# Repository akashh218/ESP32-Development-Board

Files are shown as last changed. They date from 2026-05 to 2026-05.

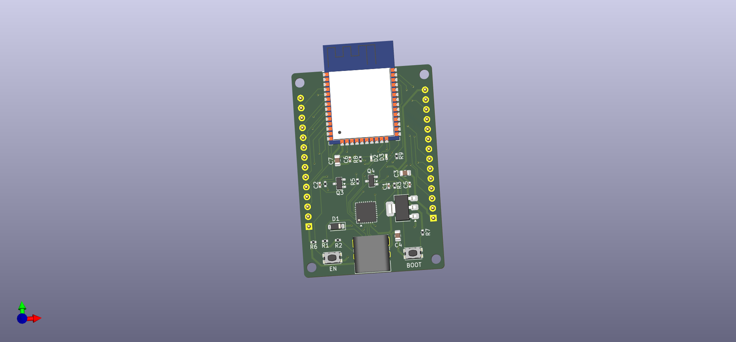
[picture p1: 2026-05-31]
esp32/esp32.png

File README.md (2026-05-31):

# ESP32-WROOM Development Board

## Overview

This project is a custom ESP32-WROOM development board designed for embedded systems, IoT applications, robotics, and rapid prototyping. The board integrates essential support circuitry required for programming, debugging, power management, and peripheral interfacing, providing a reliable platform for ESP32-based development.

## Features

* ESP32-WROOM module
* USB Type-C interface for power and programming
* USB-to-UART converter for firmware upload and serial debugging
* 3.3V regulated power supply
* Reset and Boot buttons
* GPIO breakout headers
* I²C expansion support
* UART communication interface
* Motor driver connectivity
* Status and power indicator LEDs
* Compact and PCB-friendly design

## Hardware Specifications

| Parameter | Value |
| --- | --- |
| Microcontroller | ESP32-WROOM |
| Operating Voltage | 3.3V |
| Input Power | 5V USB Type-C |
| Wireless Connectivity | Wi-Fi 802.11 b/g/n, Bluetooth Classic, BLE |
| Programming Interface | USB-to-UART |
| GPIO Access | Available through expansion headers |

## Applications

* Home Automation
* IoT Devices
* Robotics
* Sensor Networks
* Industrial Monitoring
* Wireless Data Acquisition
* Smart Control Systems
* Embedded Learning and Prototyping

## PCB Design

The PCB was designed to provide:

* Stable power delivery
* Reliable ESP32 operation
* Easy firmware flashing
* Expansion for future peripherals
* Compact layout suitable for custom projects

## Repository Contents

* Schematics
* PCB Layout Files
* Gerber Files
* Bill of Materials (BOM)
* Assembly Documentation
* Hardware Images

## Getting Started

1. Connect the board using a USB Type-C cable.
2. Install ESP32 drivers if required.
3. Open Arduino IDE, PlatformIO, or ESP-IDF.
4. Select the appropriate ESP32 board configuration.
5. Upload your firmware.
6. Monitor serial output for debugging.

## Author

Designed and developed by Akash.

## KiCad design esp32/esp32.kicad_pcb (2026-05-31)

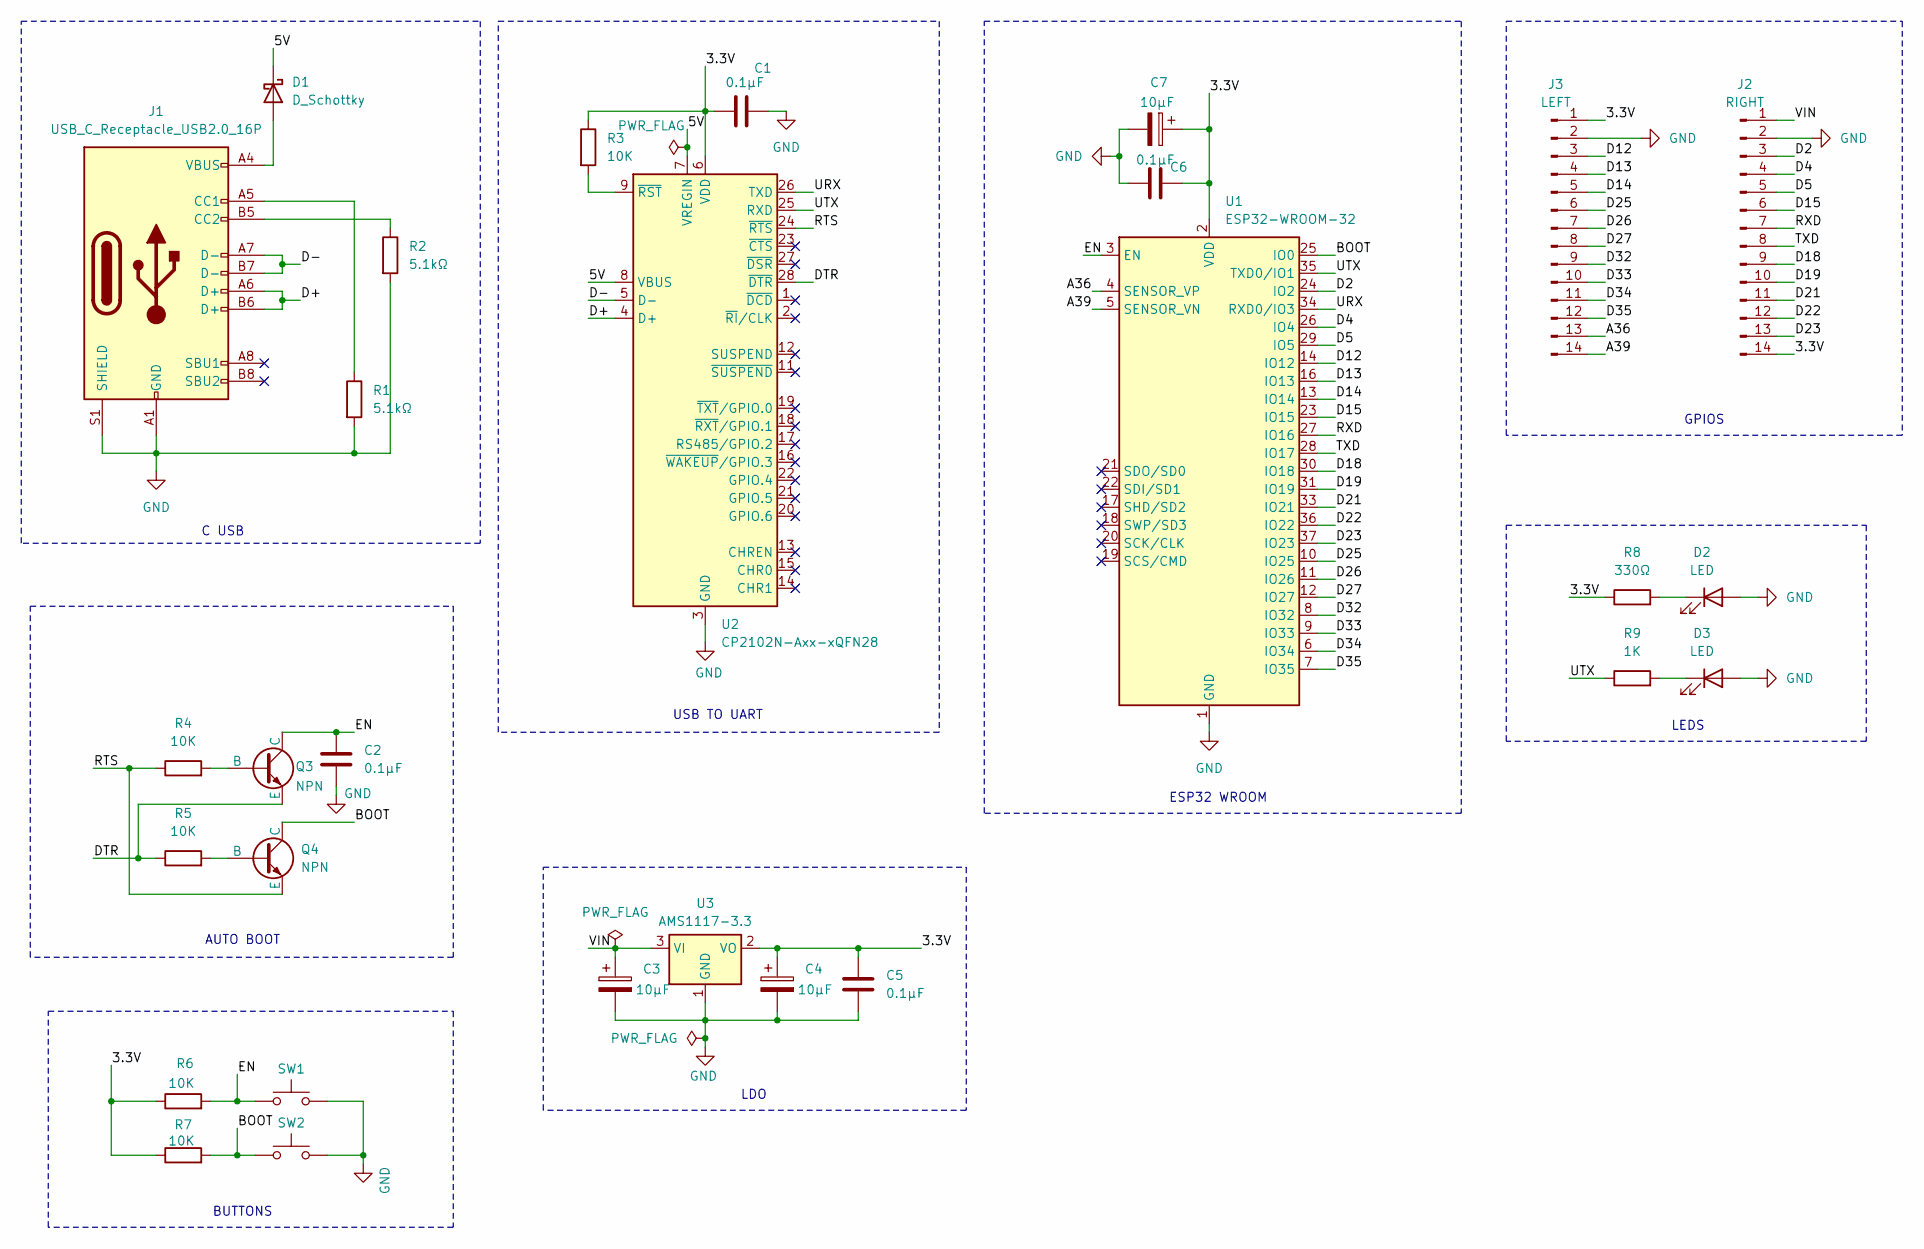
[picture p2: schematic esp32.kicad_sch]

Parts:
C1, C2, C5, C6: 0.1µF; C_0402_1005Metric
C3, C4, C7: 10µF; C_0805_2012Metric
D1: D_Schottky; D_SOD-123
D2, D3: LED; LED_0402_1005Metric
J1: USB_C_Receptacle_USB2.0_16P; USB_C_Receptacle_GCT_USB4085
J2: RIGHT; PinHeader_1x14_P2.54mm_Vertical
J3: LEFT; PinHeader_1x14_P2.54mm_Vertical
Q3, Q4: NPN; SOT-23
R1, R2: 5.1kΩ; R_0402_1005Metric
R3, R4, R5, R6, R7: 10K; R_0402_1005Metric
R8: 330Ω; R_0402_1005Metric
R9: 1K; R_0402_1005Metric
SW1, SW2: SW_Push; SW_Push_1P1T_NO_CK_KMR2
U1: ESP32-WROOM-32
U2: CP2102N-Axx-xQFN28; QFN-28-1EP_5x5mm_P0.5mm_EP3.35x3.35mm
U3: AMS1117-3.3; SOT-223-3_TabPin2

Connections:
/3.3V: C1.1, C4.1, C5.1, C6.2, C7.1, J2.14, J3.1, R3.1, R6.1, R7.1, R8.1, U1.2 (VDD), U2.6 (VDD), U3.2 (VO)
/5V: D1.1 (K), U2.7 (VREGIN), U2.8 (VBUS)
/A36: J3.13, U1.4 (SENSOR_VP)
/A39: J3.14, U1.5 (SENSOR_VN)
/BOOT: Q4.1 (C), R7.2, SW2.1, U1.25 (IO0); also elsewhere on the board
/D2: J2.3, U1.24 (IO2)
/D4: J2.4, U1.26 (IO4)
/D5: J2.5, U1.29 (IO5)
/D12: J3.3, U1.14 (IO12)
/D13: J3.4, U1.16 (IO13)
/D14: J3.5, U1.13 (IO14)
/D15: J2.6, U1.23 (IO15)
/D18: J2.9, U1.30 (IO18)
/D19: J2.10, U1.31 (IO19)
/D21: J2.11, U1.33 (IO21)
/D22: J2.12, U1.36 (IO22)
/D23: J2.13, U1.37 (IO23)
/D25: J3.6, U1.10 (IO25)
/D26: J3.7, U1.11 (IO26)
/D27: J3.8, U1.12 (IO27)
/D32: J3.9, U1.8 (IO32)
/D33: J3.10, U1.9 (IO33)
/D34: J3.11, U1.6 (IO34)
/D35: J3.12, U1.7 (IO35)
/D+: J1.A6 (D+), J1.B6 (D+), U2.4 (D+)
/D-: J1.A7 (D-), J1.B7 (D-), U2.5 (D-)
/DTR: Q3.3 (E), R5.1, U2.28 (~DTR)
/RTS: Q4.3 (E), R4.1, U2.24 (~RTS)
/RXD: J2.7, U1.27 (IO16)
/TXD: J2.8, U1.28 (IO17)
/URX: U1.34 (RXD0/IO3), U2.26 (TXD)
/UTX: R9.1, U1.35 (TXD0/IO1), U2.25 (RXD)
/VIN: C3.1, J2.1, U3.3 (VI)
unnamed: D1.2 (A), J1.A4 (VBUS), J1.A9 (VBUS), J1.B4 (VBUS), J1.B9 (VBUS)
unnamed: D2.1 (K), R8.2
unnamed: D3.1 (K), R9.2
unnamed: J1.A5 (CC1), R1.1
unnamed: J1.B5 (CC2), R2.1
unnamed: Q3.2 (B), R4.2
unnamed: Q4.2 (B), R5.2
unnamed: R3.2, U2.9 (~RST)

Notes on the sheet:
GPIOS
LEDS
AUTO BOOT
ESP32 WROOM
USB TO UART
C USB
BUTTONS
LDO

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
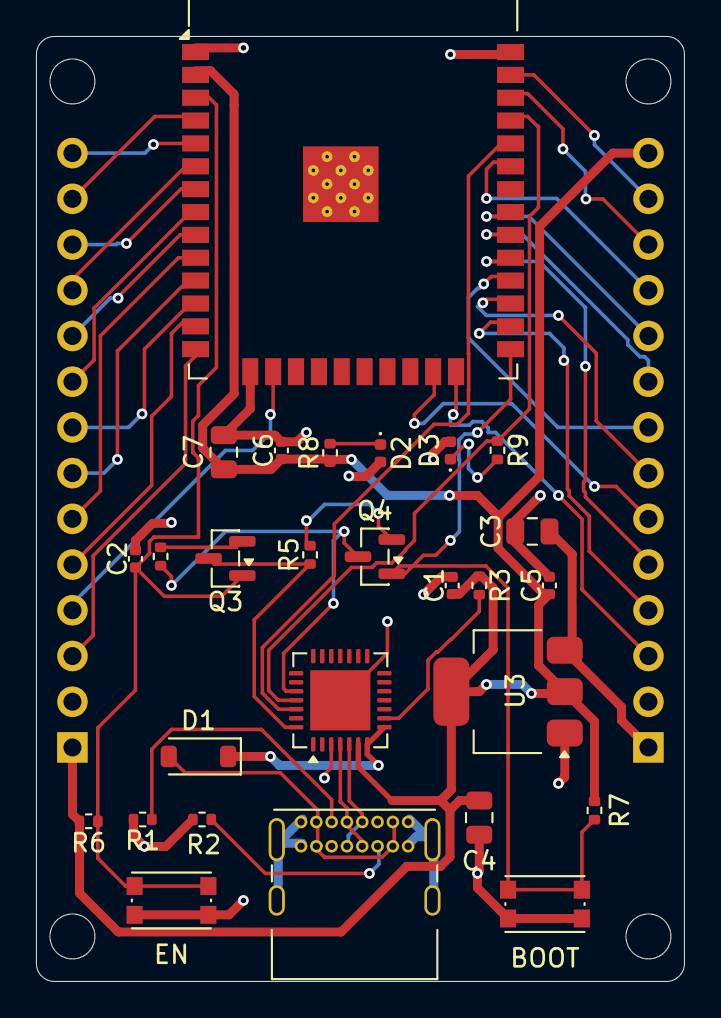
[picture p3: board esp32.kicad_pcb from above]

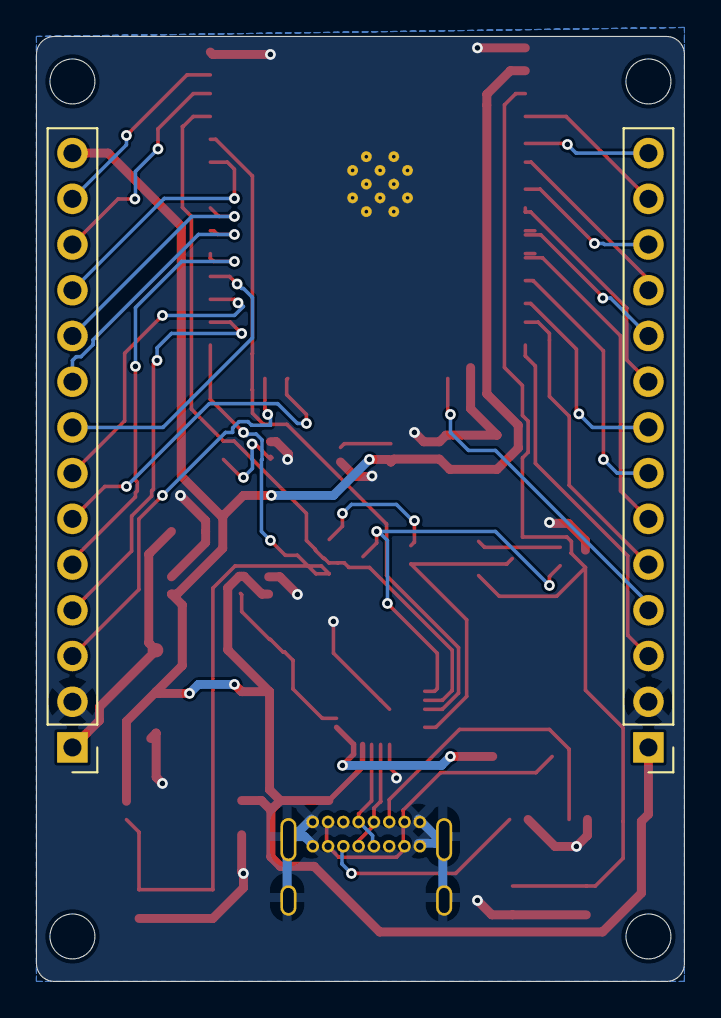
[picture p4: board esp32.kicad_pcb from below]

Board: 2 copper layers, 36.0 x 52.5 mm, 29 parts (2 on the bottom side), 43 nets.

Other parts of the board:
BOOT: SW_Push; SW_Push_1P1T_NO_CK_KMR2
EN: SW_Push; SW_Push_1P1T_NO_CK_KMR2

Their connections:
/BOOT: BOOT.1; also elsewhere on the board
